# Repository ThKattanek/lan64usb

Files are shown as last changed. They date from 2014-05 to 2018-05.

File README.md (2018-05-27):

# Lan64USB
Diese Hard- und Software ermöglicht den Transfer von Programmen vom PC zum Commodore 64 (C64).

### Hardware / Schaltplan / Treiber
Die Hardware wurde mit KiCad entwickelt. Version 4.0.7 unter Ubuntu.

Mit diesem Tool wird das Treiber Setup Programm erstellt. (LibUSB-Win32)

https://sourceforge.net/projects/libusb-win32/files/libusbK-release/

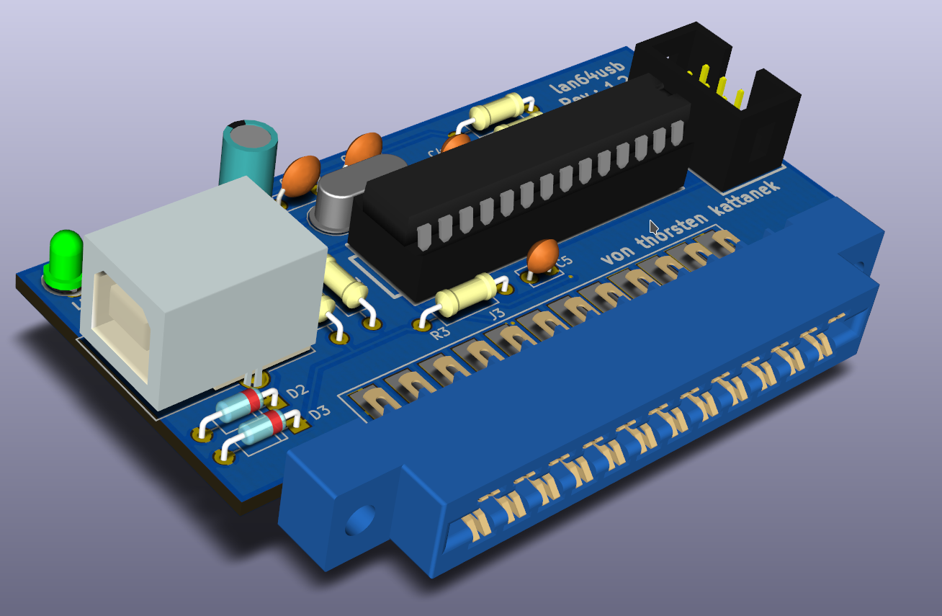
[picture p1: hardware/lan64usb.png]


### Anleitung ist hier nur für Linux User !

## Vorraussetzungen

Wird noch ergänzt !!

## Komplettes Repositorie auf dem PC laden
```bash
cd ~
git clone https://github.com/ThKattanek/lan64usb.git
```

## Erstellen der PC Anwendung "Lan64Tool"
```bash
cd ~/lan64usb/pc-software/lan64tool
mkdir build
cd build
qmake ..
make
```
## Erstellen des Konsolentools lan64-send"
```bash
cd ~/lan64usb/pc-software/konsolen_tools/lan64_send
mkdir build
cd build
qmake ..
make
```

## AVR Firmware erstellen und flashen
```bash
cd ~/lan64usb/firmware
make hex        // Erstellt das Binary
make program    // Flasht das Binary auf den avr mit avrdude (evtl. anpassen an eueren Programmer)
make clean      // Alles wieder aufräumen
```

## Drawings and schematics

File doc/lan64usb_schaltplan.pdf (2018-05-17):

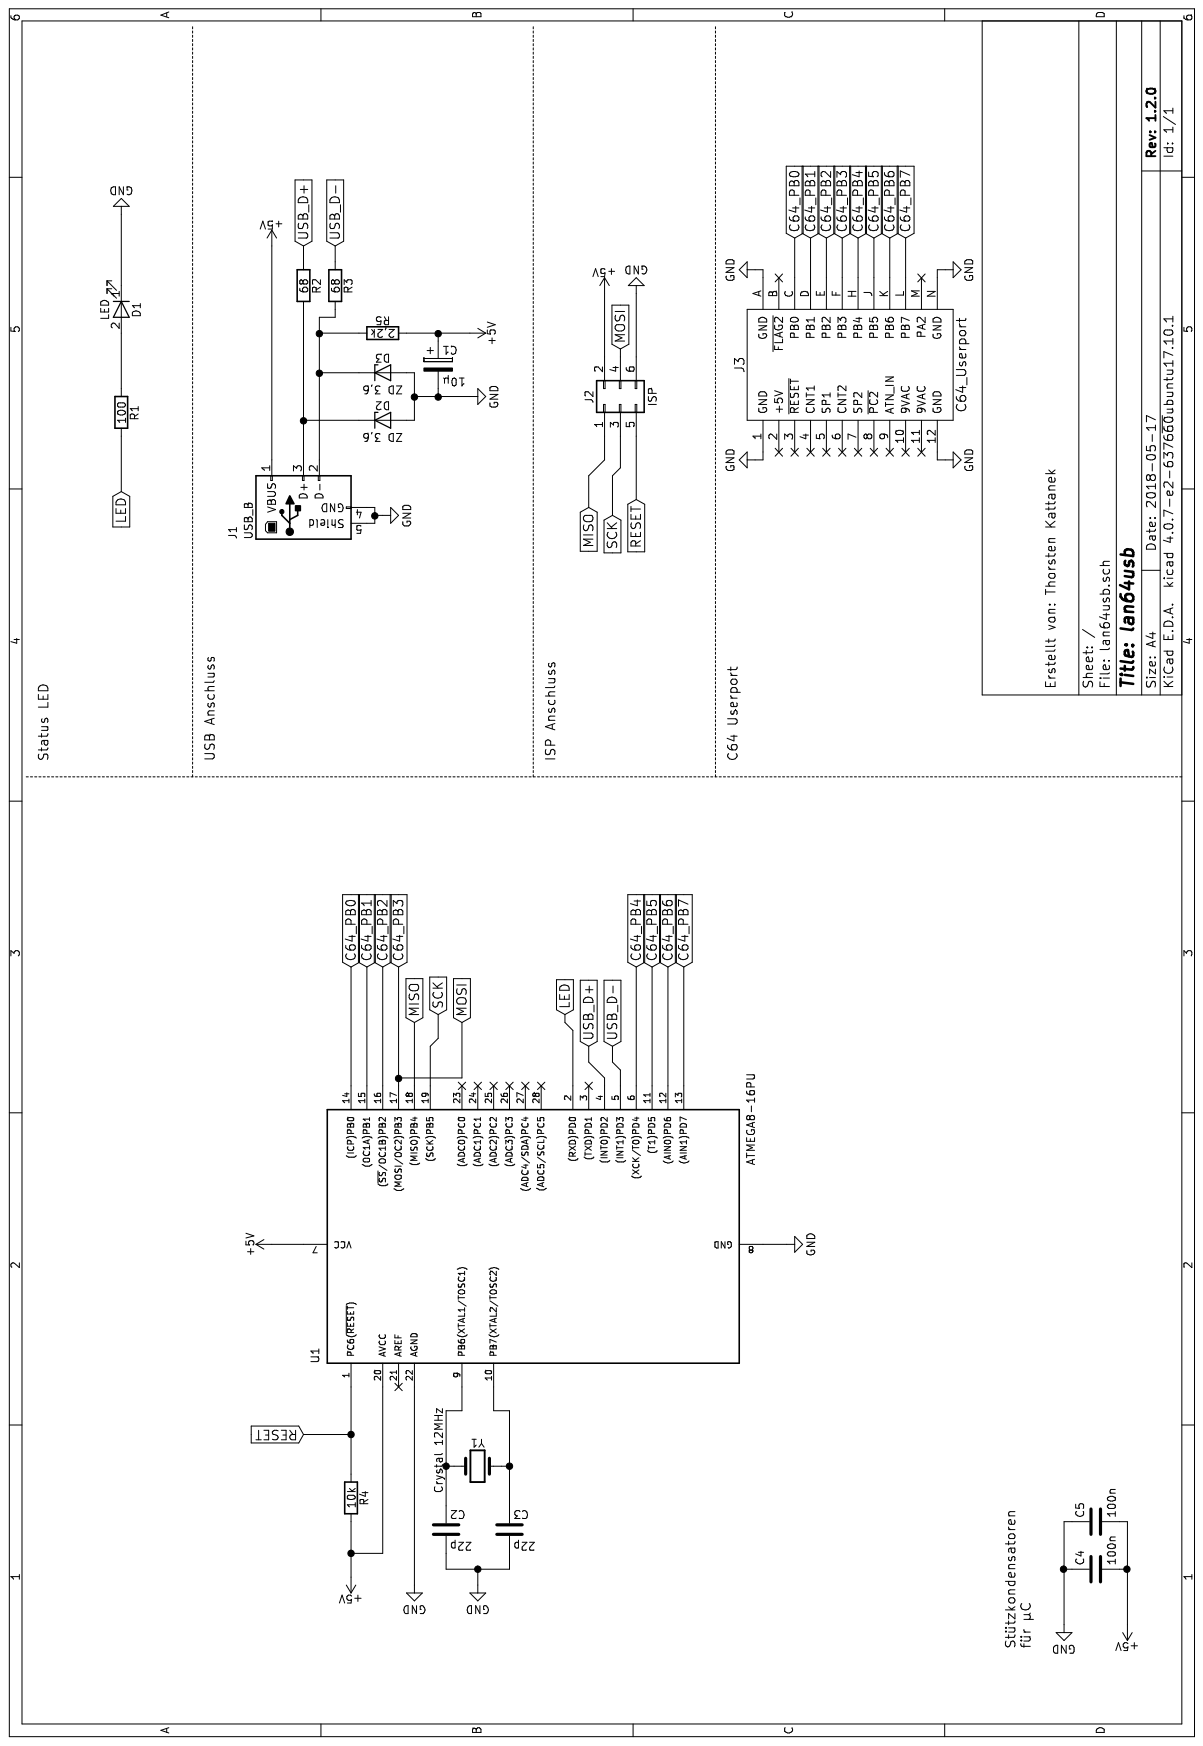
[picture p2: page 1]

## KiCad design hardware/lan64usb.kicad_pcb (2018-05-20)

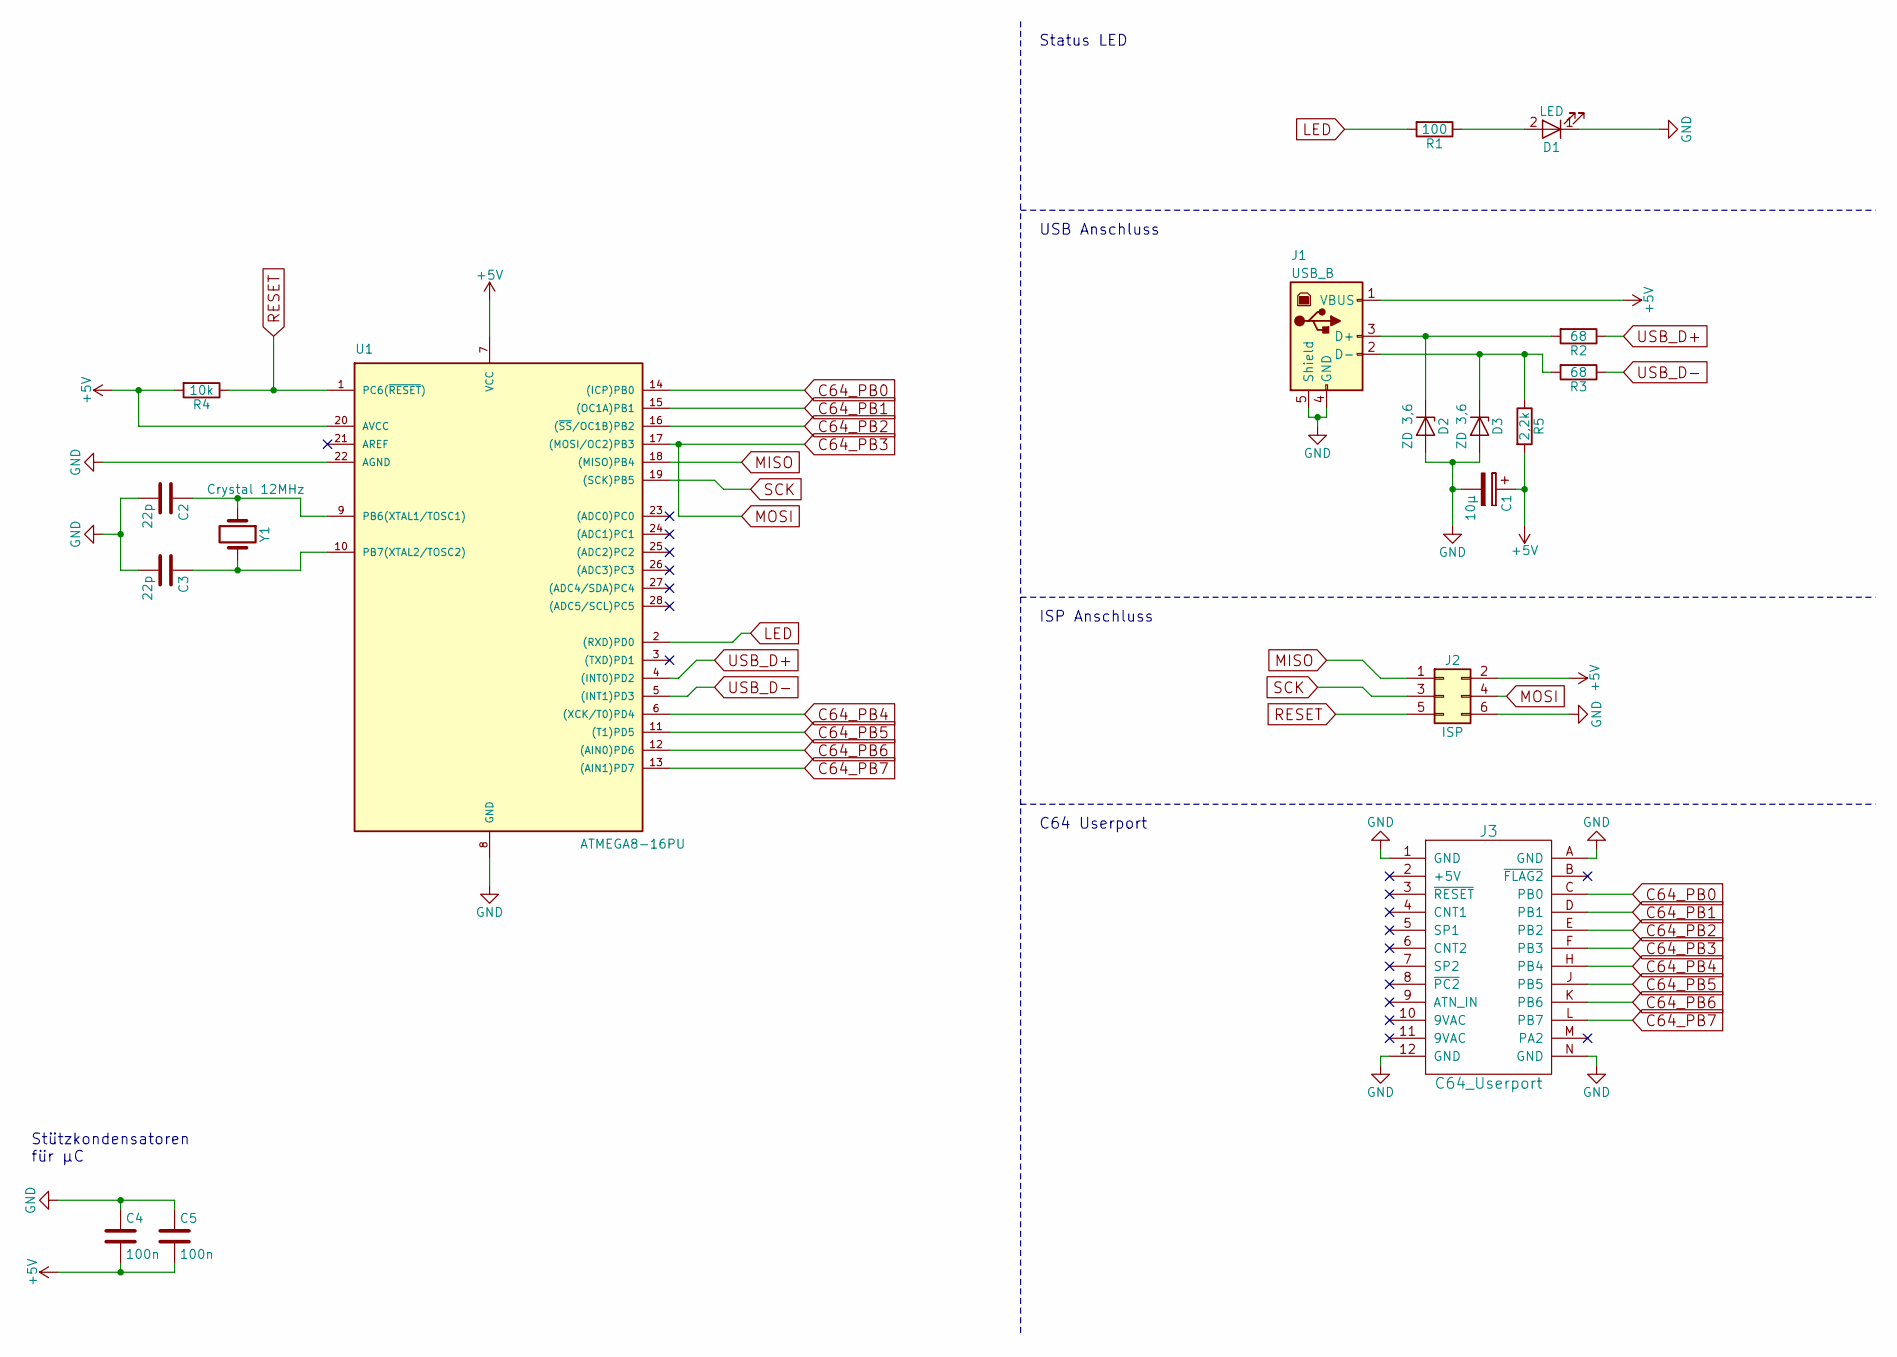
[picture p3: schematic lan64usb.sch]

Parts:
C1: 10µ; CP_5x11mm
C2, C3: 22p; C_Disc_D4.7mm_W2.5mm_P5.00mm
C4, C5: 100n; C_Disc_D3.8mm_W2.6mm_P2.50mm
D1: LED; led_3mm_green
D2, D3: ZD 3,6; D_DO-35_SOD27_P7.62mm_Horizontal
J1: USB_B
J2: ISP; vasch_strip_3x2
J3: C64_Userport; c64_userport
R1: 100; R_Axial_DIN0207_L6.3mm_D2.5mm_P10.16mm_Horizontal
R2, R3: 68; R_Axial_DIN0207_L6.3mm_D2.5mm_P10.16mm_Horizontal
R4: 10k; R_Axial_DIN0207_L6.3mm_D2.5mm_P10.16mm_Horizontal
R5: 2,2k; R_Axial_DIN0207_L6.3mm_D2.5mm_P10.16mm_Horizontal
U1: ATMEGA8-16PU; dil_28-300_socket
Y1: Crystal 12MHz; Crystal_HC49-4H_Vertical

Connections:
+5V: C1.1, C4.2, C5.2, J1.1 (VBUS), J2.2, R4.2, R5.2, U1.7 (VCC), U1.20 (AVCC)
C64_PB0: J3.C (PB0), U1.14 ((ICP)PB0)
C64_PB1: J3.D (PB1), U1.15 ((OC1A)PB1)
C64_PB2: J3.E (PB2), U1.16 ((~SS~/OC1B)PB2)
C64_PB3: J2.4, J3.F (PB3), U1.17 ((MOSI/OC2)PB3)
C64_PB4: J3.H (PB4), U1.6 ((XCK/T0)PD4)
C64_PB5: J3.J (PB5), U1.11 ((T1)PD5)
C64_PB6: J3.K (PB6), U1.12 ((AIN0)PD6)
C64_PB7: J3.L (PB7), U1.13 ((AIN1)PD7)
GND: C1.2, C2.2, C3.2, C4.1, C5.1, D1.1 (K), D2.2 (A), D3.2 (A), J1.4 (GND), J1.5 (Shield), J2.6, J3.1 (GND), J3.12 (GND), J3.A (GND), J3.N (GND), U1.8 (GND), U1.22 (AGND)
LED: R1.2, U1.2 ((RXD)PD0)
MISO: J2.1, U1.18 ((MISO)PB4)
unnamed: C2.1, U1.9 (PB6(XTAL1/TOSC1)), Y1.1
unnamed: C3.1, U1.10 (PB7(XTAL2/TOSC2)), Y1.2
unnamed: D1.2 (A), R1.1
unnamed: D2.1 (K), J1.3 (D+), R2.2
unnamed: D3.1 (K), J1.2 (D-), R3.2, R5.1
RESET: J2.5, R4.1, U1.1 (PC6(~RESET~))
SCK: J2.3, U1.19 ((SCK)PB5)
USB_D+: R2.1, U1.4 ((INT0)PD2)
USB_D-: R3.1, U1.5 ((INT1)PD3)

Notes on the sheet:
Stützkondensatoren für µC
Status LED
USB Anschluss
ISP Anschluss
C64 Userport

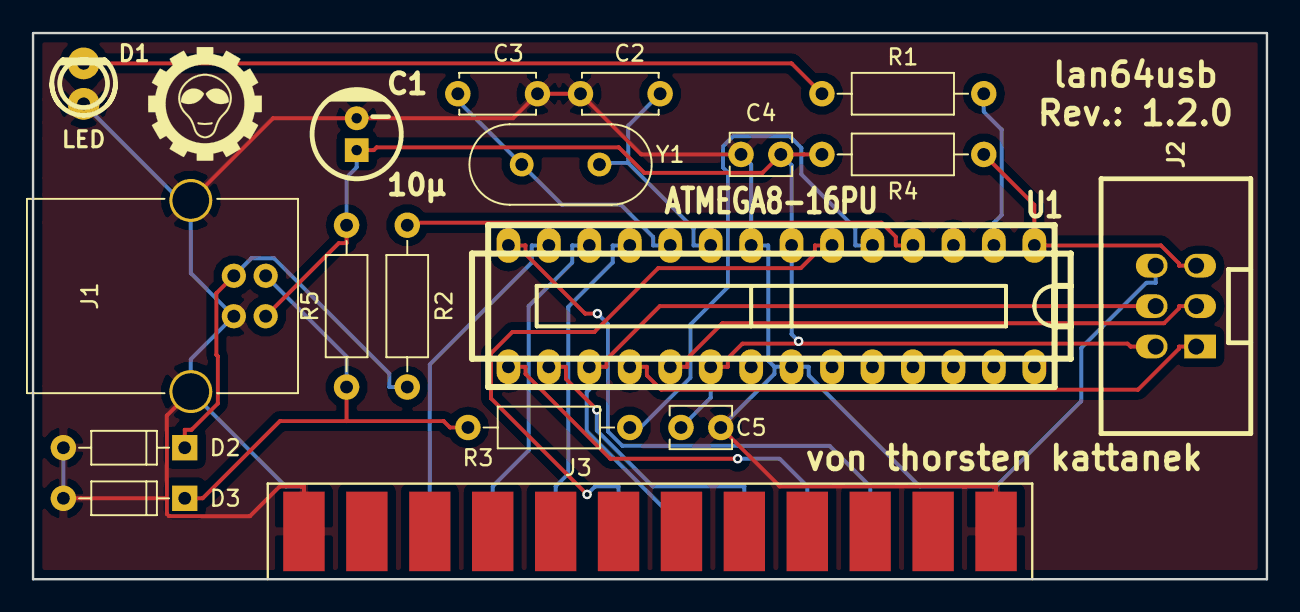
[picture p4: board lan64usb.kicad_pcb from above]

Board: 2 copper layers, 77.5 x 34.3 mm, 18 parts (0 on the bottom side), 21 nets.

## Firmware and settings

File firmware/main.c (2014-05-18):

/* Name: main.c
 * Projekt: lan64usb
 * Author: Thorsten Kattanek
 * Erstellt am: 11.05.2014
 * Copyright: Thorsten Kattanek
 * Vesrion: 1.00
 * License: GNU GPL v2 (see License.txt), GNU GPL v3 or proprietary (CommercialLicense.txt)
 *
 */

#include <avr/io.h>
#include <avr/wdt.h>
#include <avr/interrupt.h>
#include <util/delay.h>
#include <avr/pgmspace.h>   /* benötigt von usbdrv.h */
#include "usbdrv.h"

//#define CONCAT(a, b)            a ## b
//#define OUTPORT(name)           CONCAT(PORT, name)
//#define INPORT(name)            CONCAT(PIN, name)
//#define DDRPORT(name)           CONCAT(DDR, name)

volatile unsigned char buffer[128];
volatile unsigned short led_blink_counter = 0;
volatile unsigned char error_flag = 0;
volatile unsigned char transfer_status = 0;
volatile unsigned short block_anzahl;

/* ------------------------------------------------------------------------- */
/* ----------------------------- USB Interface ----------------------------- */
/* ------------------------------------------------------------------------- */

PROGMEM const char usbHidReportDescriptor[22] = {    /// USB Report descriptor
    0x06, 0x00, 0xff,              //   USAGE_PAGE (Generic Desktop)
    0x09, 0x01,                    //   USAGE (Vendor Usage 1)
    0xa1, 0x01,                    //   COLLECTION (Application)
    0x15, 0x00,                    //   LOGICAL_MINIMUM (0)
    0x26, 0xff, 0x00,              //   LOGICAL_MAXIMUM (255)
    0x75, 0x08,                    //   REPORT_SIZE (8)
    0x95, 0x80,                    //   REPORT_COUNT (128)
    0x09, 0x00,                    //   USAGE (Undefined)
    0xb2, 0x02, 0x01,              //   FEATURE (Data,Var,Abs,Buf)
    0xc0                           //   END_COLLECTION
};
/* Da wir nur ein Feature Report definieren, verwenden wir keine Report-ID's
 * Dies würde das erste Byte des Berichts sein, der Gesamte Bereich besteht aus
 * 16 Festdefinierten Daten Bytes

 0x00 - 0x07    = PortB Eingangswerte bei jew. gesetztem PortA Ausgangswert (C64 Key Matrix)
 0x08           = RESTORE Status (0 = nicht gedrückt; 1 = gedrückt)
 0x09 - 0x0F    = nicht benutzt (reserviert f. nächste Versione) */

/* Diese Variablen steuern die aktuelle Datenübertragung  */
static uchar    currentAddress;
static uchar    bytesRemaining;

/* ------------------------------------------------------------------------- */

/* usbFunctionRead() wird aufgerufen wenn der Host Daten Empfangen möchte */
uchar usbFunctionRead(uchar *data, uchar len)
{
    /*
    uint8_t i;

    if(len > bytesRemaining)
        len = bytesRemaining;

    for(i=0;i<len;i++)
    {
        data[i] = buffer[i+currentAddress];
    }

    currentAddress += len;
    bytesRemaining -= len;
    */
    return len;
}

/* ------------------------------------------------------------------------- */

void transfer_block(void)
{
    unsigned short time_out;
    unsigned char i;

    switch(transfer_status)
    {
    case 0:

        block_anzahl = (buffer[5]+1)<<1;
        transfer_status = 1;
        error_flag = 0;             // Fehler zurücksetzen

        ////////////////////// Syncronisieren mit C64 Start ///////////////////////
        ///////////////////////////////////////////////////////////////////////////

        // C64 PORTB Eingänge auf 0 setzen (PIN 3-7)
        PORTB &= ~0x08;
        PORTD &= ~0xf0;

        // Warten auf C64 PORTB Ausgänge 0 (PIN 0-2)
        time_out = 0xfff;
        while((time_out != 0) && !((PINB & 0x07) == 0x00))
        {
            time_out--;
        }

        if(time_out != 0)
        {
            // C64 PORTB Eingänge auf 1 setzen (PIN 3-7)
            PORTB |= 0x08;
            PORTD |= 0xf0;

            // Warten auf C64 PORTB Ausgänge 1 (PIN 0-2)
            time_out = 0xfff;
            while((time_out != 0) && !((PINB & 0x07) == 0x07))
            {
                time_out--;
            }

            if(time_out != 0)
            {
                // C64 PORTB Eingänge auf 0 setzen (PIN 3-7)
                PORTB &= ~0x08;
                PORTD &= ~0xf0;

                // Warten auf C64 PORTB Ausgänge 0 (PIN 0-2)
                time_out = 0xfff;
                while((time_out != 0) && !((PINB & 0x07) == 0x00))
                {
                    time_out--;
                }

                if(time_out != 0)
                {

                }

                else
                {
                    // Error !
                    transfer_status = 0;
                    PORTB = 0;
                    PORTD &= 0x0f;
                    error_flag = 1;
                    return;
                }
            }
            else
            {
                // Error !
                transfer_status = 0;
                PORTB = 0;
                PORTD &= 0x0f;
                error_flag = 1;
                return;
            }
        }
        else
        {
            // Error !
            transfer_status = 0;
            PORTB = 0;
            PORTD &= 0x0f;
            error_flag = 1;
            return;
        }

        ////////////////////// Syncronisieren mit C64 Ende ///////////////////////
        ///////////////////////////////////////////////////////////////////////////

        /// 1. 128 Bytes des Headers übertragen ///

        for(i=0;i<128;i++)
        {
            PORTD = (PORTD & 0x0f) | buffer[i] << 4;
            PORTB |= 0x08;

            // Warten auf C64 PORTB PIN2

            time_out = 0xfff;
            while((time_out != 0) && !(PINB & 0x04))
            {
                time_out--;
            }

            if(time_out != 0)
            {
                // HighNibble auf PORT legen
                PORTD = (PORTD & 0x0f) | (buffer[i] & 0xf0);
                PORTB &= ~0x08;

                time_out = 0xfff;
                while((time_out != 0) && (PINB & 0x04))
                {
                    time_out--;
                }

                if(time_out != 0)
                {
                    // Alles OK !!
                }
                else
                {
                    // Error !
                    transfer_status = 0;
                    PORTB = 0;
                    PORTD &= 0x0f;
                    error_flag = 1;
                    return;
                }
            }
            else
            {
                // Error !
                transfer_status = 0;
                PORTB = 0;
                PORTD &= 0x0f;
                error_flag = 1;
                return;
            }
        }
        block_anzahl--;
    break;

    case 1:
        for(i=0;i<128;i++)
        {
            PORTD = (PORTD & 0x0f) | buffer[i] << 4;
            PORTB |= 0x08;

            // Warten auf C64 PORTB PIN2

            time_out = 0xfff;
            while((time_out != 0) && !(PINB & 0x04))
            {
                time_out--;
            }

            if(time_out != 0)
            {
                // HighNibble auf PORT legen
                PORTD = (PORTD & 0x0f) | (buffer[i] & 0xf0);
                PORTB &= ~0x08;

                time_out = 0xfff;
                while((time_out != 0) && (PINB & 0x04))
                {
                    time_out--;
                }

                if(time_out != 0)
                {
                    // Alles OK !!
                }
                else
                {
                    // Error !
                    transfer_status = 0;
                    PORTB = 0;
                    PORTD &= 0x0f;
                    error_flag = 1;
                    return;
                }
            }
            else
            {
                // Error !
                transfer_status = 0;
                PORTB = 0;
                PORTD &= 0x0f;
                error_flag = 1;
                return;
            }
        }

        block_anzahl--;
        if(block_anzahl == 0) transfer_status = 0;

    break;
    }
}
/* ------------------------------------------------------------------------- */

/* usbFunctionWrite() wird aufgerufen wenn der Host Daten Senden möchte */
uchar   usbFunctionWrite(uchar *data, uchar len)
{
    if(bytesRemaining == 0) return 1;                       /* end of transfer */

    if(len > bytesRemaining) len = bytesRemaining;

    uchar i;

    for(i=0;i<len;i++)
    {
        buffer[currentAddress+i] = data[i];
    }

    currentAddress += len;
    bytesRemaining -= len;

    if(bytesRemaining == 0)
    {
        // Letztes Paket erhalten
        transfer_block();
    }

    return bytesRemaining == 0; /* return 1 if this was the last chunk */
}

/* ------------------------------------------------------------------------- */

usbMsgLen_t usbFunctionSetup(uchar data[8])
{
usbRequest_t    *rq = (void *)data;

    if((rq->bmRequestType & USBRQ_TYPE_MASK) == USBRQ_TYPE_CLASS){    /* HID class request */
        if(rq->bRequest == USBRQ_HID_GET_REPORT){  /* wValue: ReportType (highbyte), ReportID (lowbyte) */
            /* since we have only one report type, we can ignore the report-ID */
            bytesRemaining = 128;
            currentAddress = 0;
            return USB_NO_MSG;  /* use usbFunctionRead() to obtain data */
        }else if(rq->bRequest == USBRQ_HID_SET_REPORT){
            /* since we have only one report type, we can ignore the report-ID */
            bytesRemaining = 128;
            currentAddress = 0;
            return USB_NO_MSG;  /* use usbFunctionWrite() to receive data from host */
        }
    }else{
        /* ignore vendor type requests, we don't use any */
    }
    return 0;
}

/* ------------------------------------------------------------------------- */

void error_poll(void)
{
    if(error_flag == 0) return;
    if(led_blink_counter & 0x8000)
        PORTD |= 0x01;
    else PORTD &= 0xfe;

    led_blink_counter++;
}

int main(void)
{
    // PortB Pin 3 auf Ausgang setzen
    DDRB |= 0x08;

    // PortD Pin 4-7 und Pin 0 auf Ausgang setzen
    DDRD |= 0xf1;

    PORTB = 0;
    PORTD &= 0x0f;

    uchar   i;
    // key_buffer löschen
    for(i=0;i<2;i++)
    {
        buffer[i] = 0x00;
    }

    // Startmeldung mittels Blinken 5x
    for(i=0;i<5;i++)
    {
        PORTD |= 0x01;
        _delay_ms(40);
        PORTD &= 0xfe;
        _delay_ms(80);
    }

    // USB Initialisieren
    wdt_enable(WDTO_1S);
    usbInit();
    usbDeviceDisconnect();  // neues auflisten erzwingen, solange der Interrupt deaktiviert ist!
    i = 0;
    while(--i){             // Fake USB Disconnect für > 250 ms
        wdt_reset();
        _delay_ms(1);
    }
    usbDeviceConnect();
    sei();

    for(;;){                // Endlosschleife
        wdt_reset();
        usbPoll();
        error_poll();
    }
    return 0;
}

/* ------------------------------------------------------------------------- */

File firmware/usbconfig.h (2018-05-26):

/* Name: usbconfig.h
 * Project: V-USB, virtual USB port for Atmel's(r) AVR(r) microcontrollers
 * Author: Christian Starkjohann
 * Creation Date: 2005-04-01
 * Tabsize: 4
 * Copyright: (c) 2005 by OBJECTIVE DEVELOPMENT Software GmbH
 * License: GNU GPL v2 (see License.txt), GNU GPL v3 or proprietary (CommercialLicense.txt)
 */

#ifndef __usbconfig_h_included__
#define __usbconfig_h_included__

/*
General Description:
This file is an example configuration (with inline documentation) for the USB
driver. It configures V-USB for USB D+ connected to Port D bit 2 (which is
also hardware interrupt 0 on many devices) and USB D- to Port D bit 4. You may
wire the lines to any other port, as long as D+ is also wired to INT0 (or any
other hardware interrupt, as long as it is the highest level interrupt, see
section at the end of this file).
*/

/* ---------------------------- Hardware Config ---------------------------- */

#define USB_CFG_IOPORTNAME      D
/* This is the port where the USB bus is connected. When you configure it to
 * "B", the registers PORTB, PINB and DDRB will be used.
 */
#define USB_CFG_DMINUS_BIT      3
/* This is the bit number in USB_CFG_IOPORT where the USB D- line is connected.
 * This may be any bit in the port.
 */
#define USB_CFG_DPLUS_BIT       2
/* This is the bit number in USB_CFG_IOPORT where the USB D+ line is connected.
 * This may be any bit in the port. Please note that D+ must also be connected
 * to interrupt pin INT0! [You can also use other interrupts, see section
 * "Optional MCU Description" below, or you can connect D- to the interrupt, as
 * it is required if you use the USB_COUNT_SOF feature. If you use D- for the
 * interrupt, the USB interrupt will also be triggered at Start-Of-Frame
 * markers every millisecond.]
 */
#define USB_CFG_CLOCK_KHZ       (F_CPU/1000)
/* Clock rate of the AVR in kHz. Legal values are 12000, 12800, 15000, 16000,
 * 16500, 18000 and 20000. The 12.8 MHz and 16.5 MHz versions of the code
 * require no crystal, they tolerate +/- 1% deviation from the nominal
 * frequency. All other rates require a precision of 2000 ppm and thus a
 * crystal!
 * Since F_CPU should be defined to your actual clock rate anyway, you should
 * not need to modify this setting.
 */
#define USB_CFG_CHECK_CRC       0
/* Define this to 1 if you want that the driver checks integrity of incoming
 * data packets (CRC checks). CRC checks cost quite a bit of code size and are
 * currently only available for 18 MHz crystal clock. You must choose
 * USB_CFG_CLOCK_KHZ = 18000 if you enable this option.
 */

/* ----------------------- Optional Hardware Config ------------------------ */

/* #define USB_CFG_PULLUP_IOPORTNAME   D */
/* If you connect the 1.5k pullup resistor from D- to a port pin instead of
 * V+, you can connect and disconnect the device from firmware by calling
 * the macros usbDeviceConnect() and usbDeviceDisconnect() (see usbdrv.h).
 * This constant defines the port on which the pullup resistor is connected.
 */
/* #define USB_CFG_PULLUP_BIT          4 */
/* This constant defines the bit number in USB_CFG_PULLUP_IOPORT (defined
 * above) where the 1.5k pullup resistor is connected. See description
 * above for details.
 */

/* --------------------------- Functional Range ---------------------------- */
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

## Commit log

2014-05-10 Start des Projektes
2014-05-13 - Nach Fehlgeschlagener Uerbertragung musste der Adapter getrennt werden. Dies ist nicht mehr noetig
2018-04-15 trutf8 bei den Texten der Message Ausgaben hinzugefügt. Somit wird bei immer die richtige Codierung des Textes für das jeweilige System eingesetzt.
2018-05-15 repository struktur geändert
    [lan64usb.kicad_pcb, lan64usb.sch]
2018-05-15 Angefangen den Schaltplan in KiCAD zu zeichnen.
    [lan64usb.sch]
2018-05-16 Schaltplan in KiCad fertig gezeichnet. Rev auf 1.1.0 gesetzt.
    [lan64usb.sch]
2018-05-17 Schaltplan für DIP Bauteile angepasst. Rev.: 1.2.0
    [lan64usb.sch]
2018-05-17 Alle Footprints zugeordnet und Net Liste erstellt.
    [lan64usb.sch]
2018-05-17 Ein erstes PCB Layout erstellt.
    [lan64usb.dsn]
2018-05-17 3D Ansicht hinzugefügt. Stecker fehlt noch!
    [lan64usb.kicad_pcb]
2018-05-20 3D Modell des Userport Steckers eingefügt.
    [lan64usb.kicad_pcb]
2018-05-27 lan64tool: open(), openDevice() und closeDevice() fertig umgestellt auf libusb-1.0
